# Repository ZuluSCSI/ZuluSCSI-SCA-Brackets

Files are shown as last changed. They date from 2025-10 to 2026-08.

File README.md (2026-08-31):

## Bracket for ZuluSCSI with 3.5" hard drive holes
### Designed Specifically to align the SCA connector on the ZuluSCSI Wide SCA board, but can be used with other ZuluSCSI boards

### Rev 2026
Directory: ZuluSCSI-Wide-SCA-pcb-direct-rev2026+

This FreeCAD design is for the ZuluSCSI Wide SCA rev 2026 which directly connects to an SCA receptacle using the PCB edge of the ZuluSCSI.
The brackets go on the bottom of the board while the shroud goes on the top, chip side, of the board.
The screws go through the shroud and into the bracket on the SCA side. On the SD/USB side screws will probably need washers before going
through ZuluSCSI into the brackets on the bottom.

### Direct 50
Directory: ZuluSCSI-Compact-with-SCA-Direct-50

This FreeCAD design is specifically for a narrow compact soldered to an SCA adapter directly.

### Rev 2025
Directory: ZuluSCSI-Wide-SCA-works-with-non-SCA-too

These are FreeCAD designs made for 3D printing and include the STL files for
the left and right bracket. Both brackets are have labels SCSI and SD
which correspond to the orientation of the ZuluSCSI. SCSI label should be 
closest the SCA connector side or any other SCSI connector. The SD label
should be closest to the SD Card side of the board.

When screwing in the ZuluSCSI Wide SCA, the IC chips of the circuit board
on the same side as the screw heads with the SCA connector below.

The screws holes for the hard drive mounts are standard 3.5" HDDs screws (6-32 UNC).
The screws holes for mounting the ZuluSCSI on the brackets are for 4-40 UNC 1/4 inch screws,
the closes metric version is a M3 screw 6mm in length.

There is also an alignment bracket which slides into the bottom hard drive screw holes
making it easier to screw on the left and right brackets to the ZuluSCSI. The alignment
bracket can be turned 180 degrees and still mount properly.

ZuluSCSI SCA Brackets © 2025 by Rabbit Hole Computing is licensed under CC BY-SA 4.0. To view a copy of this license, visit https://creativecommons.org/licenses/by-sa/4.0/ or read [LICENSE.txt](LICENSE.txt)
License Logo


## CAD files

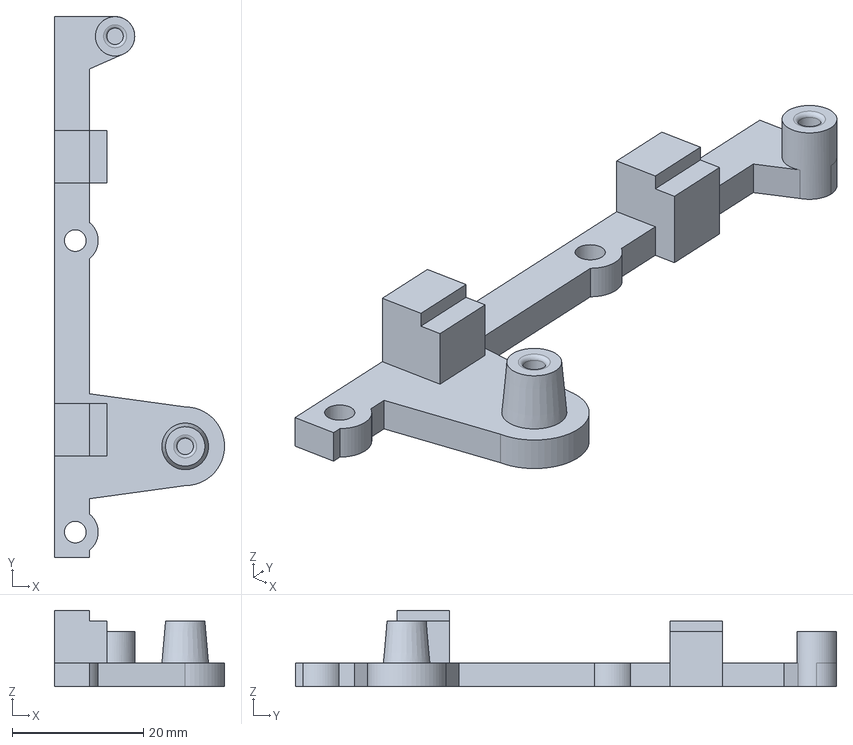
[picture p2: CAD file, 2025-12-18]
ZuluSCSI-Compact-with-SCA-Direct-50/Bracket-Left.FCStd
25.9 x 82.5 x 11.6 mm

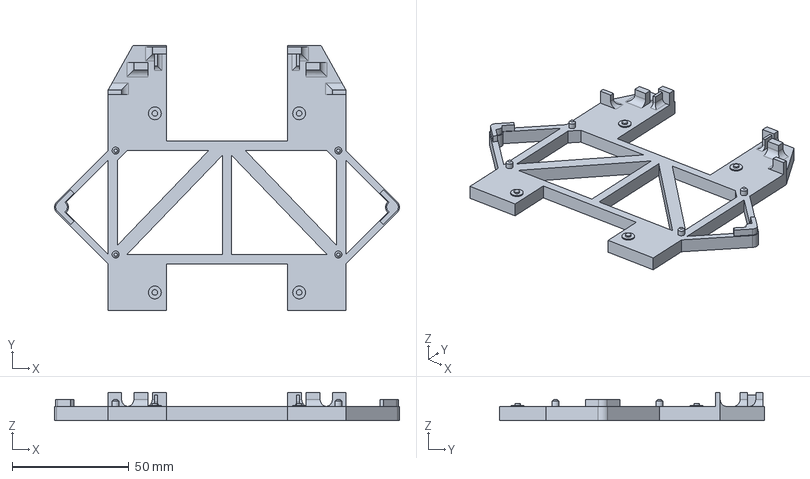
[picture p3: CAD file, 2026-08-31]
ZuluSCSI-Wide-SCA-pcb-direct-rev2026+/Alignment-Bracket.FCStd
147.6 x 113.5 x 12.0 mm

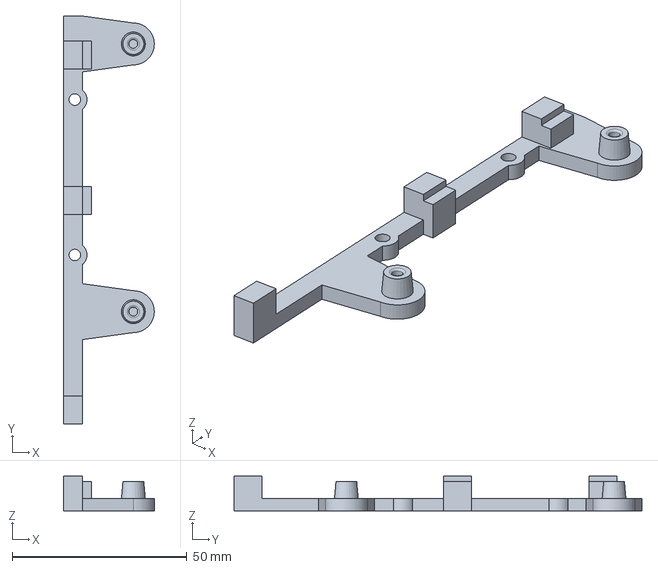
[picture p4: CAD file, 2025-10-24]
ZuluSCSI-Wide-SCA-works-with-non-SCA-too/Bracket-Left.FCStd
25.9 x 116.8 x 10.0 mm

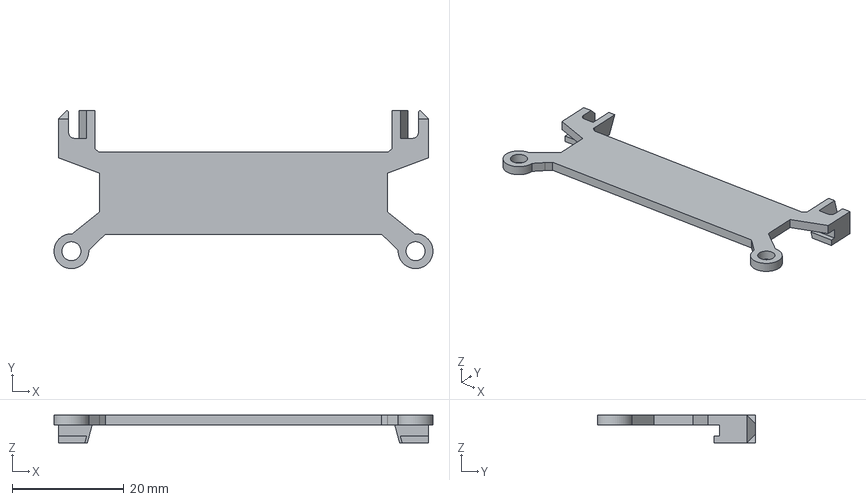
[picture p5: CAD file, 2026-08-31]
ZuluSCSI-Wide-SCA-pcb-direct-rev2026+/ZuluSCSI-Wide-SCA-2026a-shroud.step
68.0 x 28.4 x 5.00 mm

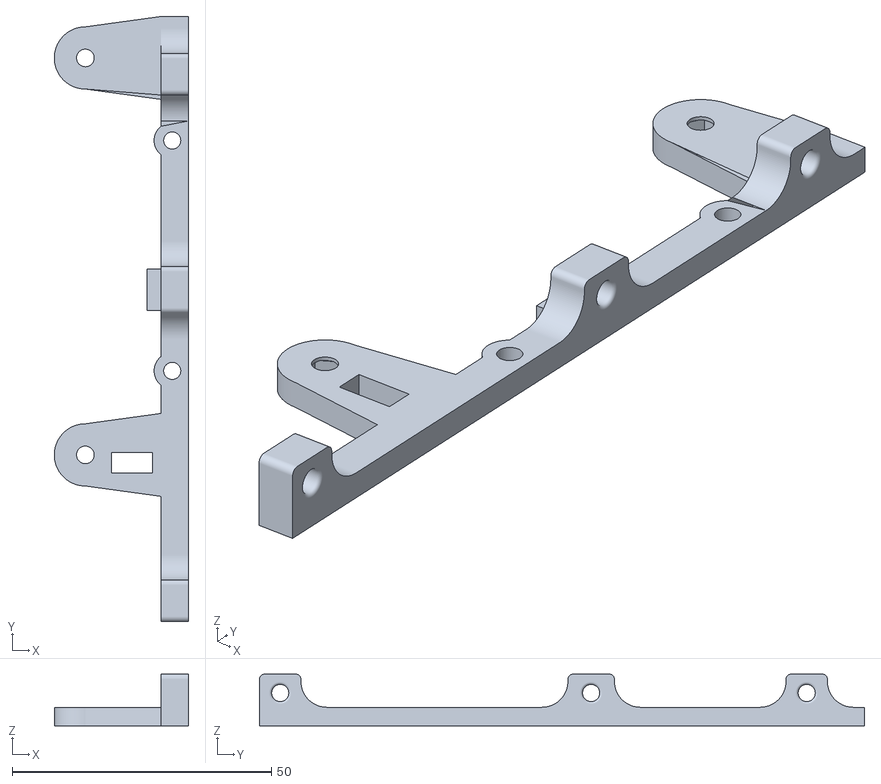
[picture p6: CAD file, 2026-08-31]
ZuluSCSI-Wide-SCA-pcb-direct-rev2026+/Bracket-Right.stl
25.9 x 116.8 x 10.0

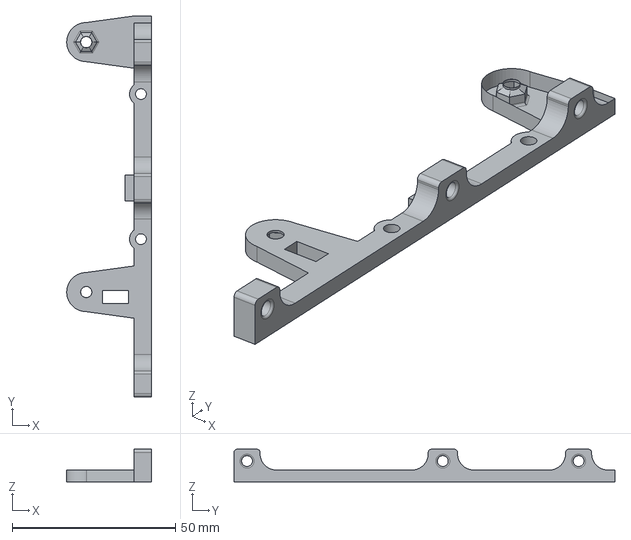
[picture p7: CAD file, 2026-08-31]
ZuluSCSI-Wide-SCA-pcb-direct-rev2026+/ZuluSCSI-Wide-SCA-2026a-bracket-right.step
25.9 x 116.8 x 10.0 mm

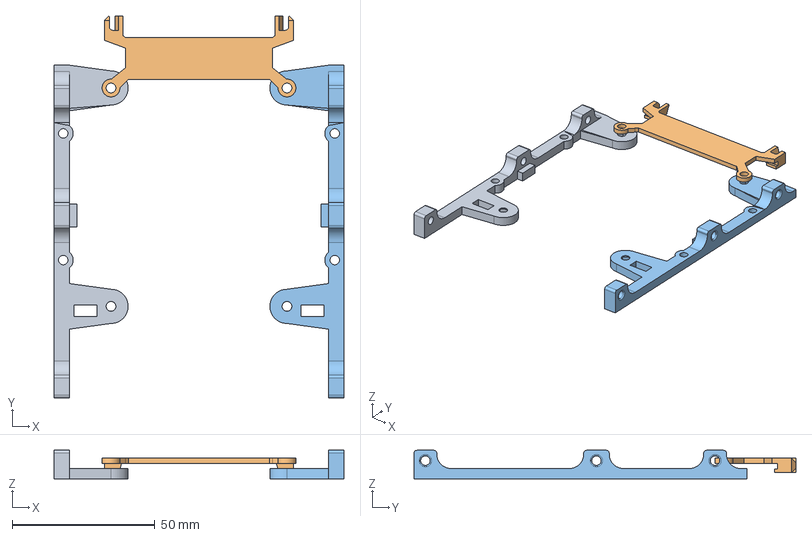
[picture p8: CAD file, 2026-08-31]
ZuluSCSI-Wide-SCA-pcb-direct-rev2026+/Brackets-and-Shroud.FCStd
101.6 x 134.0 x 10.0 mm
orientation-post-part
Body (Mirror #1)

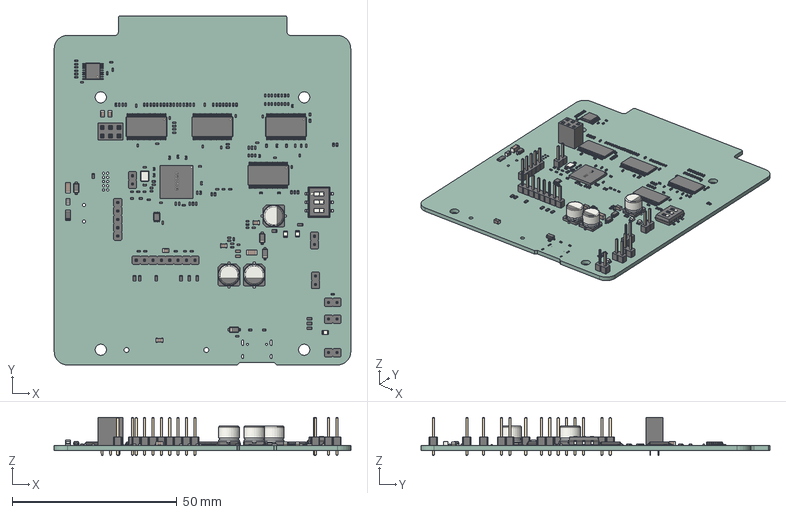
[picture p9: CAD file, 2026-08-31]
ZuluSCSI-Wide-SCA-pcb-direct-rev2026+/ZuluSCSI-Wide-SCA-2026a-PCB.step
90.0 x 105.9 x 11.6 mm
Fuse_1206_3216Metric
D_SOD-123 x 4
R_0402_1005Metric x 76
R_0603_1608Metric x 12
C_0402_1005Metric x 45
C_0805_2012Metric x 6
PinHeader_1x02_P2.54mm_Vertical x 6
L_0402_1005Metric x 28
L_0805_2012Metric
CP_Elec_6.3x5.9 x 3
C_0603_1608Metric x 2
SW_DIP_SPSTx03_Slide_6.7x9.18mm_W8.61mm_P2.54mm_LowProfile
Crystal_SMD_3225-4Pin_3.2x2.5mm
LED_0805_2012Metric x 3
RP2350_QFN80
VSSOP-8_2.3x2mm_P0.5mm
TSSOP-48_6.1x12.5mm_P0.5mm x 4
PinSocket_2x03_P2.54mm_Vertical
PinHeader_1x08_P2.54mm_Vertical
C_1206_3216Metric x 2
PinHeader_1x05_P2.54mm_Vertical
TSSOP-16_4.4x5mm_P0.65mm
zuluscsi_PCB

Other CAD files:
ZuluSCSI-Compact-with-SCA-Direct-50/Bracket-Left-Body.stl
ZuluSCSI-Wide-SCA-works-with-non-SCA-too/Bracket-Left-Body.stl
ZuluSCSI-Wide-SCA-pcb-direct-rev2026+/Connector-Shroud.stl
ZuluSCSI-Wide-SCA-works-with-non-SCA-too/Bracket-Right-Body-no-text.stl
ZuluSCSI-Wide-SCA-pcb-direct-rev2026+/Alignment-Bracket-Body.stl
ZuluSCSI-Wide-SCA-works-with-non-SCA-too/Bracket-Right.FCStd
ZuluSCSI-Wide-SCA-works-with-non-SCA-too/Bracket-Right-Body.stl
ZuluSCSI-Wide-SCA-works-with-non-SCA-too/Bracket-Left-Body-no-text.stl
ZuluSCSI-Wide-SCA-pcb-direct-rev2026+/Bracket-Left.stl
ZuluSCSI-Wide-SCA-pcb-direct-rev2026+/ZuluSCSI-Wide-SCA-2026a-bracket-left.step

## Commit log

2025-10-24 First commit
    What to send to the printer
    With text indicating direction of ZuluSCSI board
    Bracket-Left-Body.stl
    Bracket-Right-Body.stl
    Without text
    Bracket-Left-Body-no-text.stl
    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
    [Alignment Bracket-Body.stl, Alignment-Bracket.FCStd, Bracket-Left-Body-no-text.stl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]
2025-12-18 STLs for the ZuluSCSI Wide SCA rev 2026+ board
    In the directory `ZuluSCSI-Wide-SCA-pcb-direct [rev 2026a+]`
    contains the FreeCAD file `Brackets-and-Shroud.FCStd` which is the
    source for STLs:
    `Bracket_Left.stl`
    `Bracket_Right.stl`
    `Connector-Shroud.stl`.
    The files are for the ZuluSCSI Wide SCA rev 2026a and future boards
    that connect directly to the SCA connector using the ZuluSCSI's pcb
    edge. The Connector shroud does a pretty good job at avoiding inserting
    the ZuluSCSI upside down.
    While the brackets has the correct height alignment for the PCB edge
    SCA connector and holes for mounting in a hard drive bay.
    As of now the 1/4" 440 screw is a bit to long for the SD/USB side
    of the bracket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
    [Alignment-Bracket-Body.stl, Alignment-Bracket.FCStd, Bracket-Left-Body-no-text.stl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]
2026-08-21 Reinforce shroud
    Increase the amount of material between the left and right sides.
    [Brackets-and-Shroud.FCStd, Connector-Shroud.stl]
2026-08-21 Decrease shroud thickness and PCB gap height
    The shroud was too thick for a certain SCA socket. Thinned it 0.5mm on
    both sides for proper clearance. Decreased the PCB gap between the tabs
    and support plane for better fitment.
    Exported a .step file of the shroud.
    [Brackets-and-Shroud.FCStd, Connector-Shroud.stl, ZuluSCSI-Wide-SCA-2026a-shroud.step]
2026-08-25 Switch to M3 screws and nuts
    [Alignment-Bracket-Body.stl, Alignment-Bracket.FCStd, Bracket-Left.stl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]
2026-08-31 Use directory name without brackets or spaces
    [Alignment-Bracket-Body.stl, Alignment-Bracket.FCStd, Bracket-Left.stl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]
2026-08-31 Remove special characters and spaces from directory name
    [Alignment-Bracket-Body.stl, Alignment-Bracket.FCStd, Bracket-Left.stl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]
2026-08-31 Alignment bracket adjustments
    [Alignment-Bracket-Body.stl, Alignment-Bracket.FCStd]
2026-09-01 Re-name step file to explicitly describe what it is a representation of
    [ZuluSCSI-Wide-SCA-2026a-PCB.step]
